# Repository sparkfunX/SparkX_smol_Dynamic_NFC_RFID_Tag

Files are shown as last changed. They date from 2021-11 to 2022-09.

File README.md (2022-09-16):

# SparkX smôl Dynamic NFC/RFID Tag

SparkX smôl Dynamic NFC/RFID Tag (SPX-18991) (https://www.sparkfun.com/products/18991)

[*SparkX smôl Dynamic NFC/RFID Tag (SPX-18991)*](https://www.sparkfun.com/products/18991)

You might be wondering why we would make an NFC/RFID tag peripheral board for smôl? The STMicroelectronics ST25FV64KC is a _**dynamic**_ Near Frequency Communication / Radio Frequency Identification tag IC with 64Kbit (8KByte) of on-board EEPROM memory. It has an I<sup>2</sup>C interface which the smôl processor board can use to read and write to the EEPROM memory. But the memory can also be read and written to over the RF link _while your smôl ecosystem is in deep sleep_! This means it is perfect for: contactless data storage and collection; and for configuration.

## Repository Contents

- **/Hardware** - Eagle design files
- **LICENSE.md** contains the licence information

## Product Versions

- [SPX-18991](https://www.sparkfun.com/products/18991) - Original SparkX Release.

## License Information

This product is _**open source**_!

Please review the LICENSE.md file for license information.

If you have any questions or concerns on licensing, please contact technical support on our [SparkFun forums](https://forum.sparkfun.com/viewforum.php?f=123).

Distributed as-is; no warranty is given.

- Your friends at SparkFun.

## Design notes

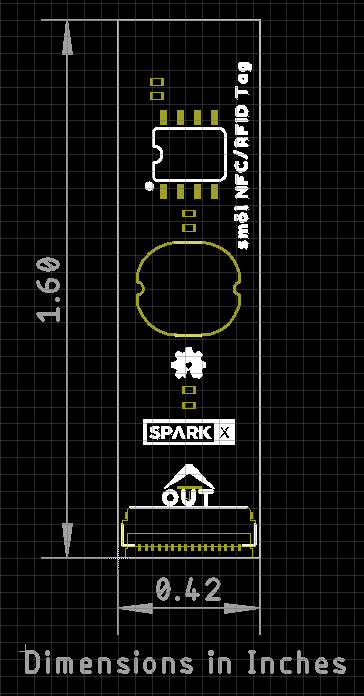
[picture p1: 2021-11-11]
img/Dimensions.png

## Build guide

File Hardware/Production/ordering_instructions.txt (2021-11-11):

panel size, 193x137mm
PCB thickness, 0.8mm
number of layers, 4
soldermask color, Black
silkscreen color, White
oz copper, 1oz
finish, HASL lead free
stencils, top+bottom
pcs per panel, 48
min trace width, 0.1524mm / 0.0060in
min drill size, 0.3000mm / 0.0118in
filename to layer stackup 1/2/3/4: GTL, GL2, GL3, GBL

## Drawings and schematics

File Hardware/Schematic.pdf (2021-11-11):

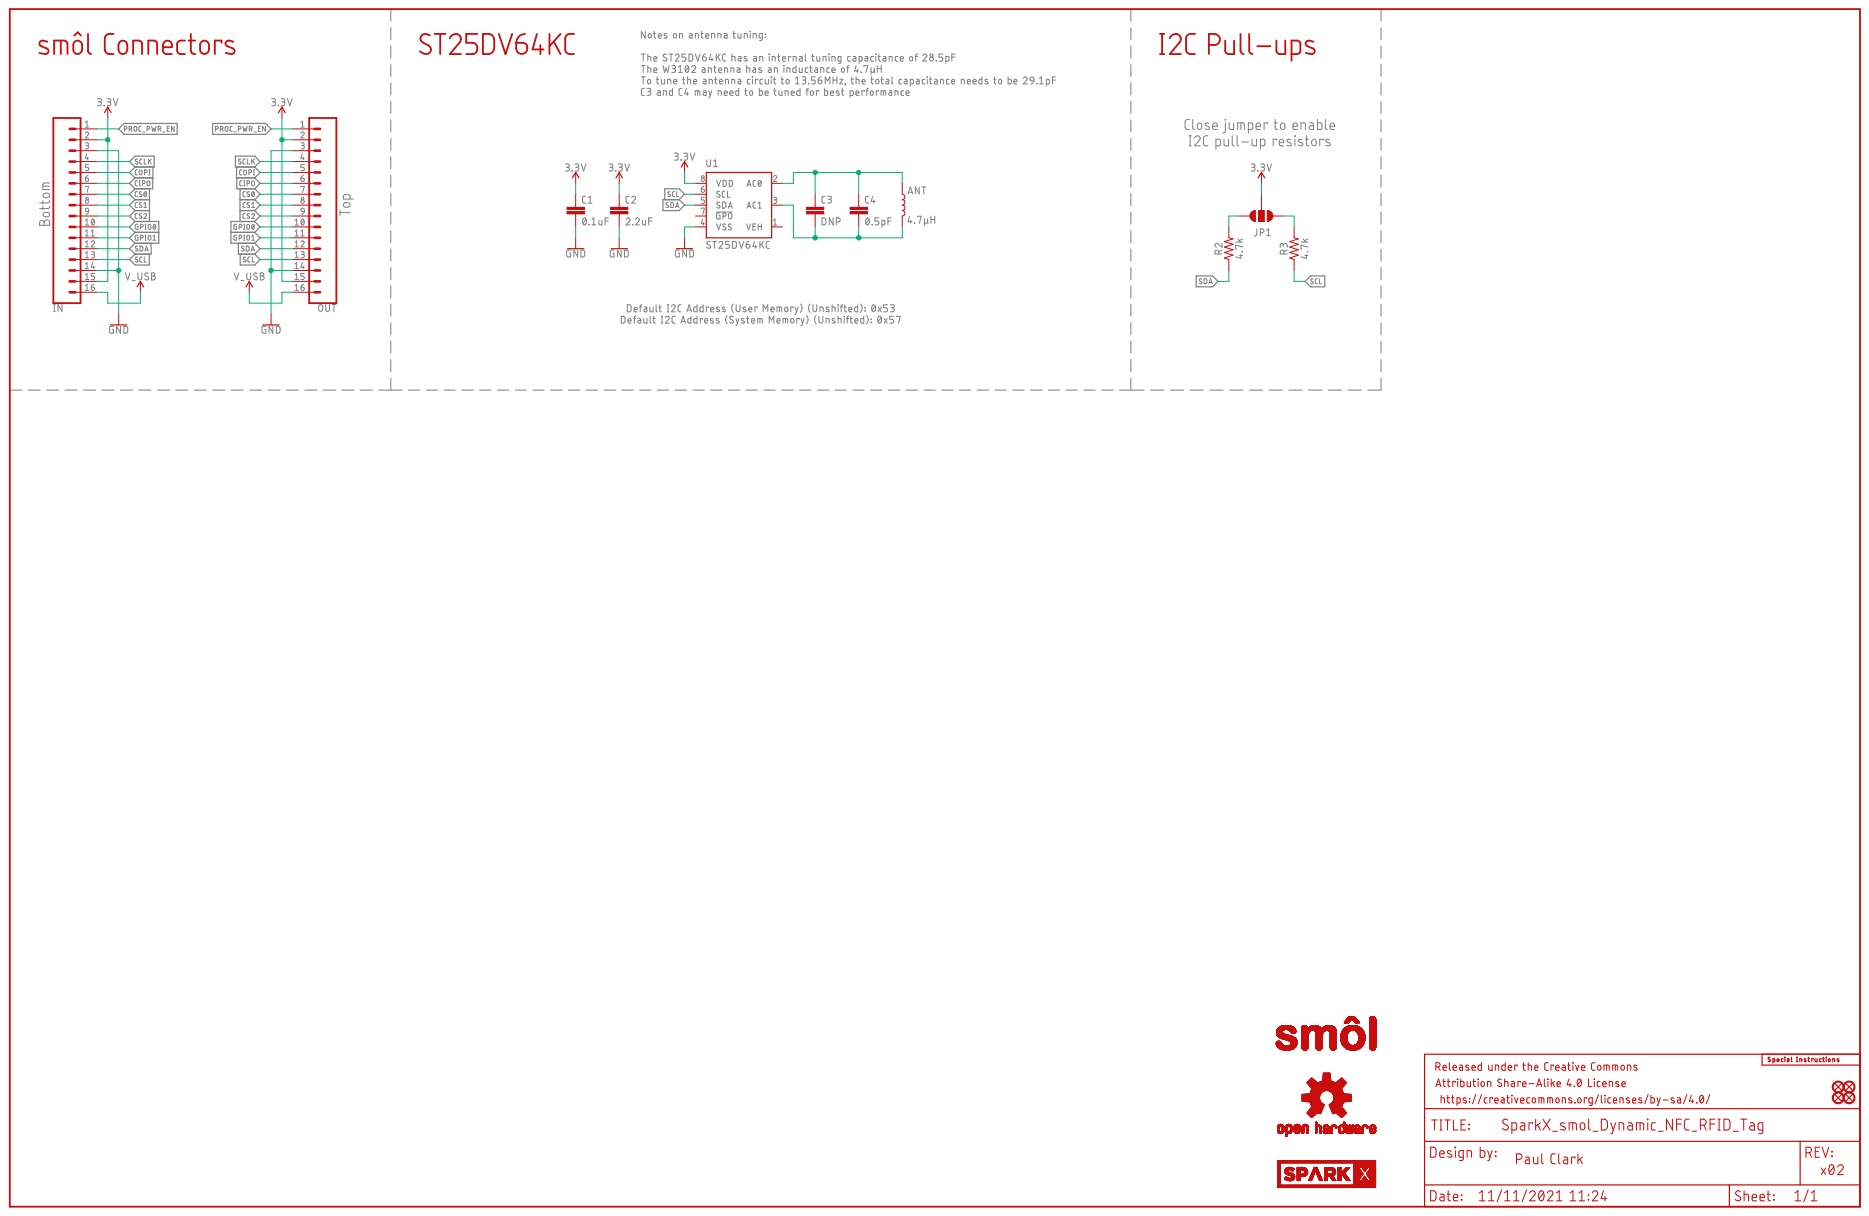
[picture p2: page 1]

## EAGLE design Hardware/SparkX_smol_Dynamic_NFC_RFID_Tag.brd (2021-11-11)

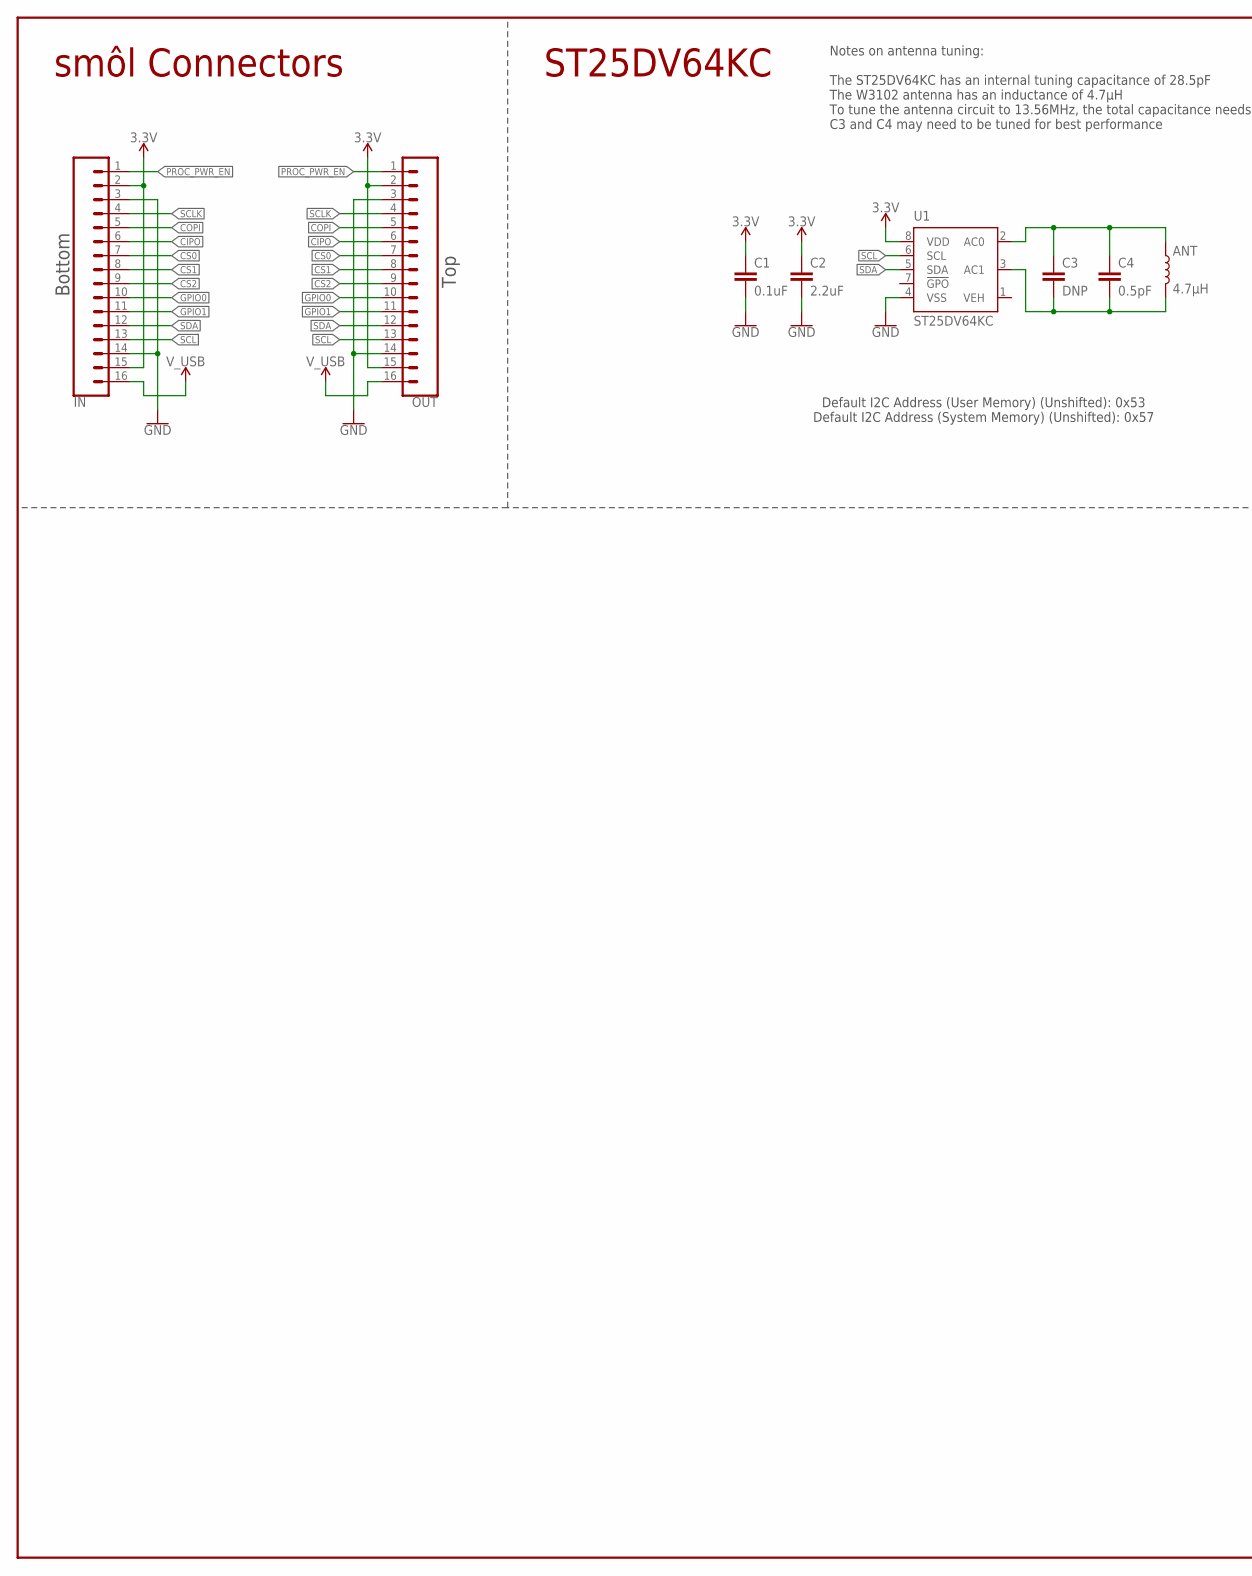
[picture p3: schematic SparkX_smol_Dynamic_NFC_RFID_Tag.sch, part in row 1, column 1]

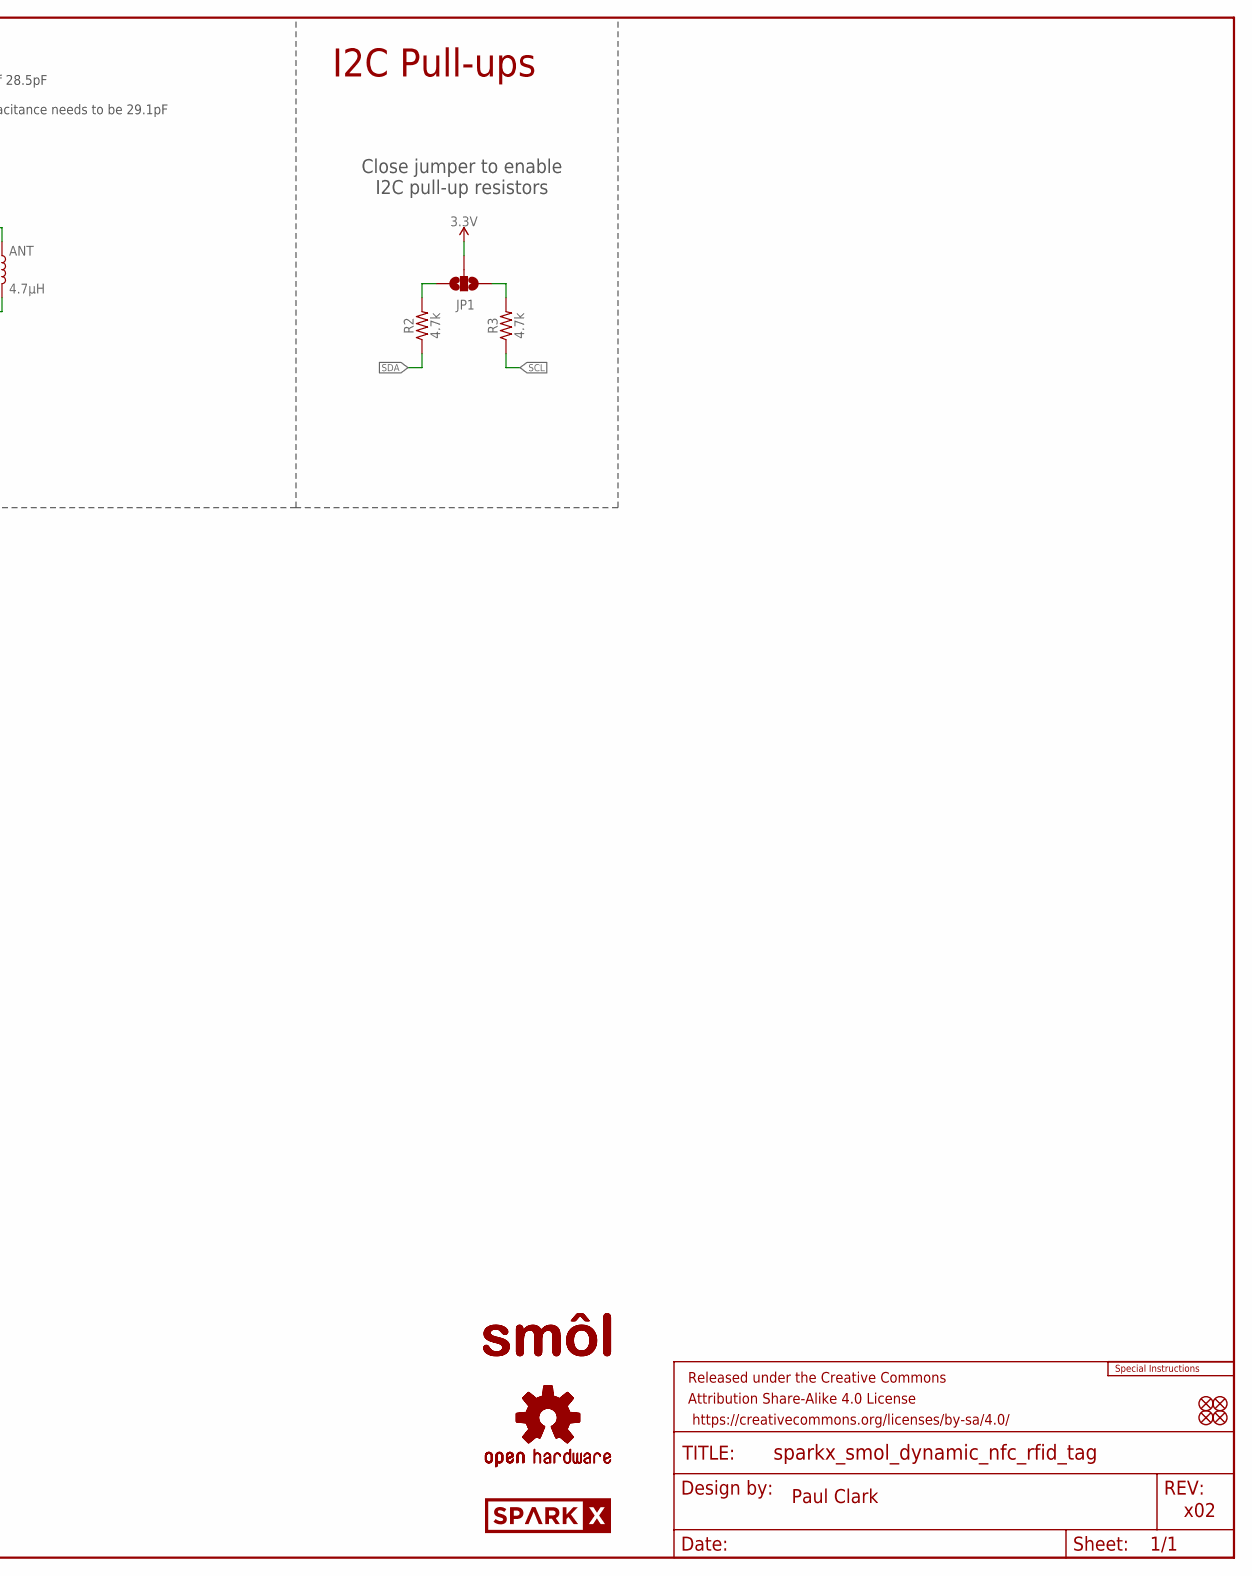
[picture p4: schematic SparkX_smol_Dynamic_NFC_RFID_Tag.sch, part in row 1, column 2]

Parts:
ANT: 4.7μH; W3102
C1: 0.1uF; 0402-TIGHT
C2: 2.2uF; 0402-TIGHT
C3: DNP; 0402-TIGHT_NO_CREAM
C4: 0.5pF; 0402-TIGHT
FD1, FD2, FD3, FD4: FIDUCIALUFIDUCIAL; FIDUCIAL-MICRO
FRAME1: FRAME-LEDGER; CREATIVE_COMMONS
IN: CONN_16FPC_16_0.5MM; FPC_16_0.5MM
JP1: JUMPER-SMT_3_NO_SILK; SMT-JUMPER_3_NO_SILK
LOGO1: SPECIAL_INSTRUCTIONS-ORDERING; ORDERING_INSTRUCTIONS
LOGO2, LOGO3: OSHW-LOGOMINI; OSHW-LOGO-MINI
OUT: CONN_16FPC_16_0.5MM; FPC_16_0.5MM
R2, R3: 4.7k; 0402-TIGHT
U1: ST25DV64KC; SO08
U$1: SPARKX-LOGO3; SPARKX-SMALL
U$3, U$9: SMOL_LOGOSMALL; SMOL_SMALL

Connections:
3.3V: C1.1, C2.1, IN.2, IN.15, JP1.2, OUT.2, OUT.15, U1.8 (VDD)
CIPO: IN.6, OUT.6
COPI: IN.5, OUT.5
CS0: IN.7, OUT.7
CS1: IN.8, OUT.8
CS2: IN.9, OUT.9
GND: C1.2, C2.2, IN.3, IN.14, OUT.3, OUT.14, U1.4 (VSS)
GPIO0: IN.10, OUT.10
GPIO1: IN.11, OUT.11
unnamed: ANT.2, C3.2, C4.2, U1.3 (AC1)
unnamed: ANT.1, C3.1, C4.1, U1.2 (AC0)
unnamed: JP1.3, R2.2
unnamed: JP1.1, R3.2
PROC_PWR_EN: IN.1, OUT.1
SCL: IN.13, OUT.13, R3.1, U1.6 (SCL)
SCLK: IN.4, OUT.4
SDA: IN.12, OUT.12, R2.1, U1.5 (SDA)
VEH: U1.1 (VEH)
V_USB: IN.16, OUT.16

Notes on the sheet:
Paul Clark
x02
smôl Connectors
Top
Bottom
ST25DV64KC
Default I2C Address (User Memory) (Unshifted): 0x53 Default I2C Address (System Memory) (Unshifted): 0x57
Notes on antenna tuning: The ST25DV64KC has an internal tuning capacitance of 28.5pF The W3102 antenna has an inductance of 4.7µH To tune the antenna circuit to 13.56MHz, the total capacitance needs to be 29.1pF C3 and C4 may need to be tuned for best performance
Close jumper to enable I2C pull-up resistors
I2C Pull-ups

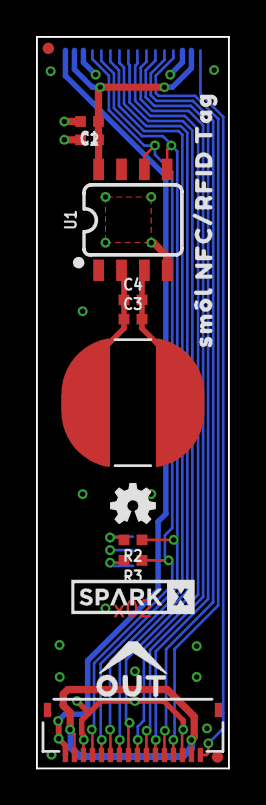
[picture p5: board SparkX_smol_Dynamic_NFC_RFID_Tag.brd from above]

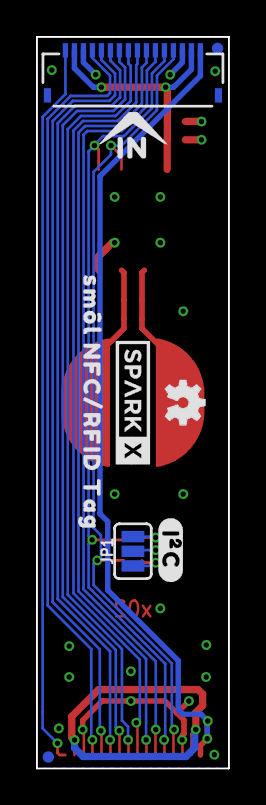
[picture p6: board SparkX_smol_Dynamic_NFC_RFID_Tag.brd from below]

Board: 4 copper layers, 10.7 x 40.6 mm, 28 parts (10 on the bottom side), 18 nets.

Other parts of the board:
U$2, U$4: SM�L_NFC#RFID_TAG0
U$5: #I�C#0
U$8: IN0
U$17: OUT0
U$20: SPARKX-LOGO3; SPARKX-SMALL

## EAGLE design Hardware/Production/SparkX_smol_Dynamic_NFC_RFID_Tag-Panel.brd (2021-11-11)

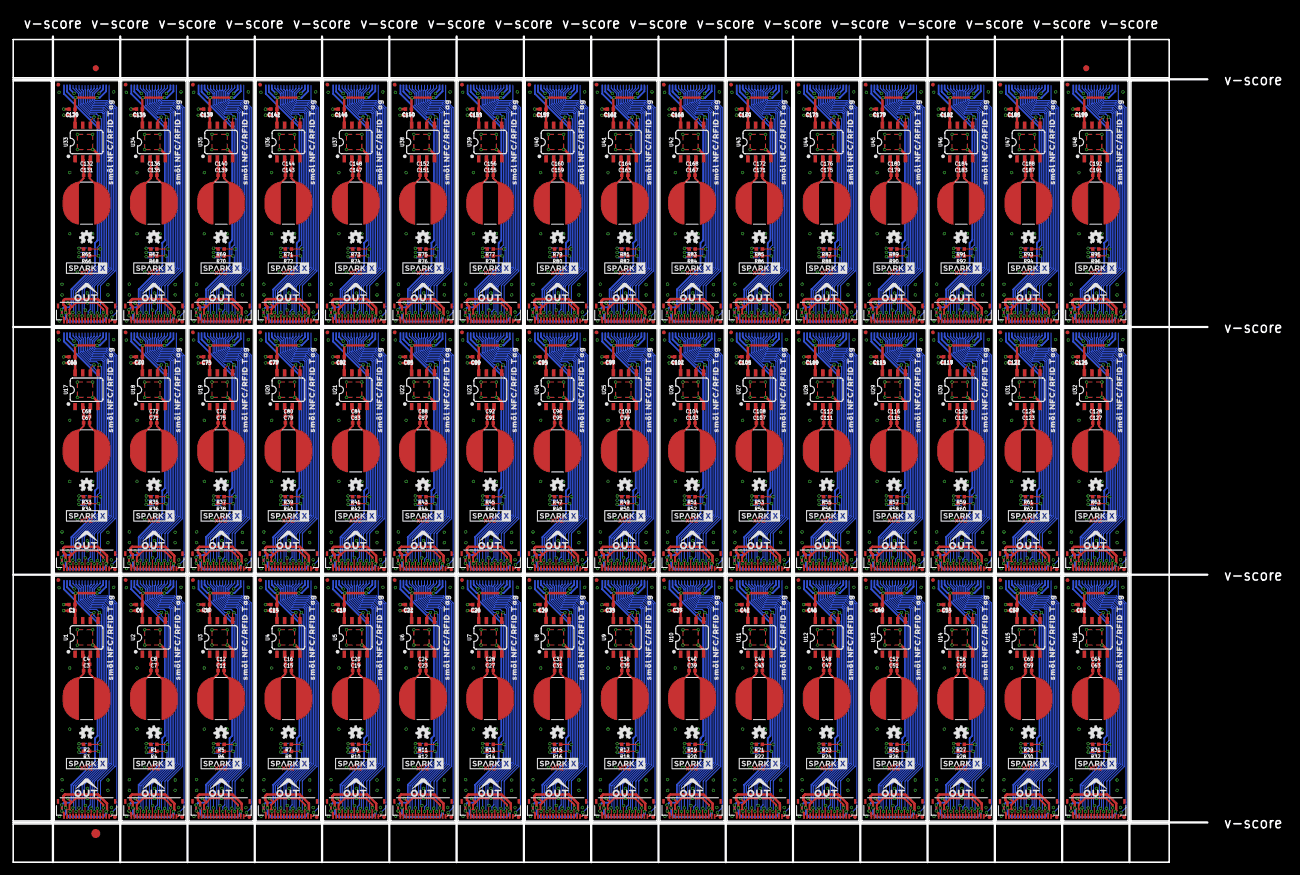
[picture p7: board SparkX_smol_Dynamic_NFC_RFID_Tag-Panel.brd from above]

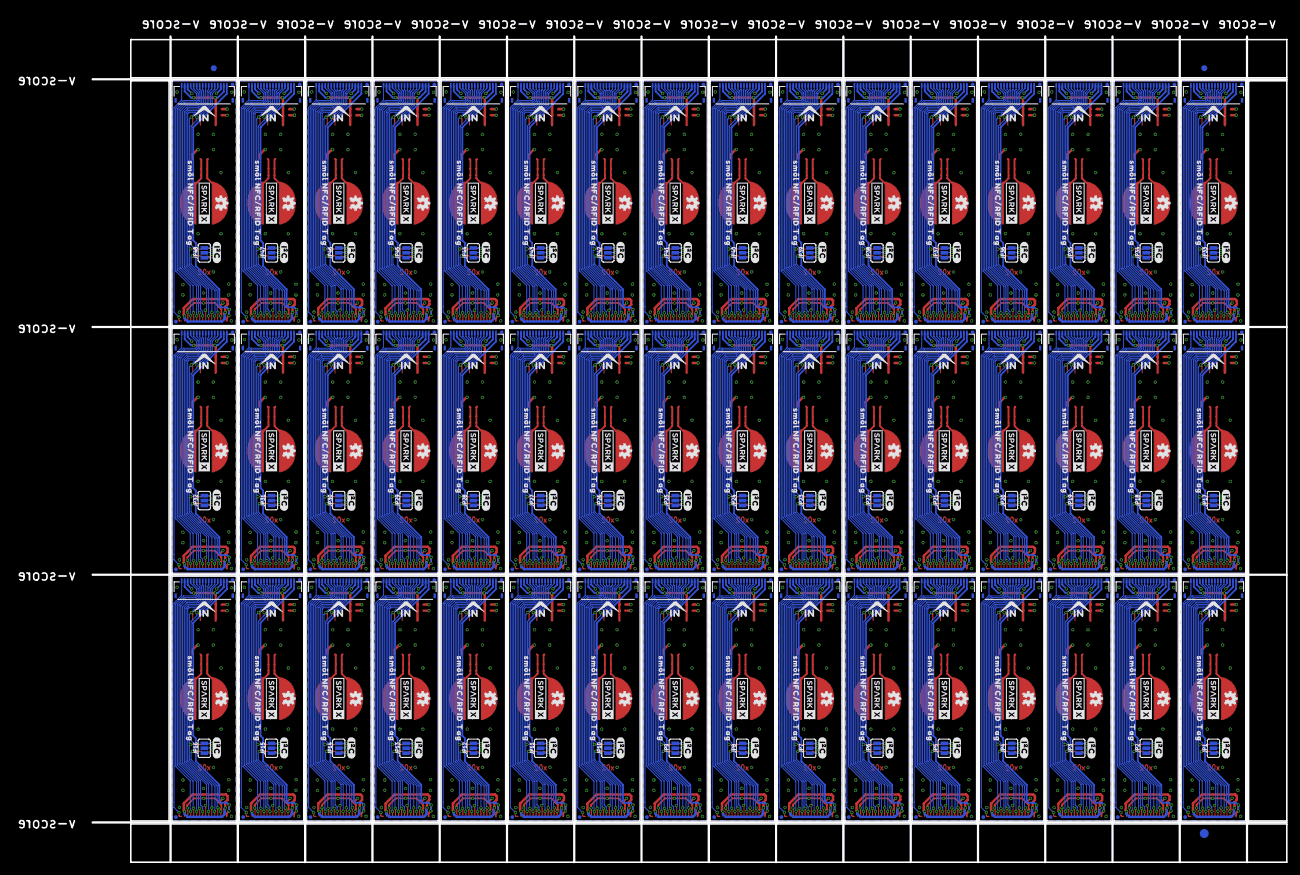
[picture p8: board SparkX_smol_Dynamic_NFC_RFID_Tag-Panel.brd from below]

Board: 4 copper layers, 198.4 x 137.2 mm, 1254 parts (483 on the bottom side), 864 nets.

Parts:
ANT, ANT1, ANT2, ANT3, ANT4, ANT5, ANT6, ANT7, ANT8, ANT9, ANT10, ANT11, ANT12, ANT13, ANT14, ANT15, ANT16, ANT17, ANT18, ANT19, ANT20, ANT21, ANT22, ANT23, ANT24, ANT25, ANT26, ANT27, ANT28, ANT29, ANT30, ANT31, ANT32, ANT33, ANT34, ANT35, ANT36, ANT37, ANT38, ANT39, ANT40, ANT41, ANT42, ANT43, ANT44, ANT45, ANT46, ANT47: 4.7μH; W3102
C1, C6, C10, C14, C18, C22, C26, C30, C34, C38, C42, C46, C50, C54, C58, C62, C66, C70, C74, C78, C82, C86, C90, C94, C98, C102, C106, C110, C114, C118, C122, C126, C130, C134, C138, C142, C146, C150, C154, C158, C162, C166, C170, C174, C178, C182, C186, C190: 0.1uF; 0402-TIGHT
C2, C5, C9, C13, C17, C21, C25, C29, C33, C37, C41, C45, C49, C53, C57, C61, C65, C69, C73, C77, C81, C85, C89, C93, C97, C101, C105, C109, C113, C117, C121, C125, C129, C133, C137, C141, C145, C149, C153, C157, C161, C165, C169, C173, C177, C181, C185, C189: 2.2uF; 0402-TIGHT
C3, C7, C11, C15, C19, C23, C27, C31, C35, C39, C43, C47, C51, C55, C59, C63, C67, C71, C75, C79, C83, C87, C91, C95, C99, C103, C107, C111, C115, C119, C123, C127, C131, C135, C139, C143, C147, C151, C155, C159, C163, C167, C171, C175, C179, C183, C187, C191: DNP; 0402-TIGHT_NO_CREAM
C4, C8, C12, C16, C20, C24, C28, C32, C36, C40, C44, C48, C52, C56, C60, C64, C68, C72, C76, C80, C84, C88, C92, C96, C100, C104, C108, C112, C116, C120, C124, C128, C132, C136, C140, C144, C148, C152, C156, C160, C164, C168, C172, C176, C180, C184, C188, C192: 0.5pF; 0402-TIGHT
E$1, E$2, E$3, E$4: FIDUCIAL-1X2
E$5, E$6: FIDUCIAL-1.5X3
FD1, FD2, FD3, FD4, FD5, FD6, FD7, FD8, FD9, FD10, FD11, FD12, FD13, FD14, FD15, FD16, FD17, FD18, FD19, FD20, FD21, FD22, FD23, FD24, FD25, FD26, FD27, FD28, FD29, FD30, FD31, FD32, FD33, FD34, FD35, FD36, FD37, FD38, FD39, FD40, FD41, FD42, FD43, FD44, FD45, FD46, FD47, FD48, FD49, FD50, FD51, FD52, FD53, FD54, FD55, FD56, FD57, FD58, FD59, FD60, FD61, FD62, FD63, FD64, FD65, FD66, FD67, FD68, FD69, FD70, FD71, FD72, FD73, FD74, FD75, FD76, FD77, FD78, FD79, FD80, FD81, FD82, FD83, FD84, FD85, FD86, FD87, FD88, FD89, FD90, FD91, FD92, FD93, FD94, FD95, FD96, FD97, FD98, FD99, FD100, FD101, FD102, FD103, FD104, FD105, FD106, FD107, FD108, FD109, FD110, FD111, FD112, FD113, FD114, FD115, FD116, FD117, FD118, FD119, FD120, FD121, FD122, FD123, FD124, FD125, FD126, FD127, FD128, FD129, FD130, FD131, FD132, FD133, FD134, FD135, FD136, FD137, FD138, FD139, FD140, FD141, FD142, FD143, FD144, FD145, FD146, FD147, FD148, FD149, FD150, FD151, FD152, FD153, FD154, FD155, FD156, FD157, FD158, FD159, FD160, FD161, FD162, FD163, FD164, FD165, FD166, FD167, FD168, FD169, FD170, FD171, FD172, FD173, FD174, FD175, FD176, FD177, FD178, FD179, FD180, FD181, FD182, FD183, FD184, FD185, FD186, FD187, FD188, FD189, FD190, FD191, FD192: FIDUCIALUFIDUCIAL; FIDUCIAL-MICRO
IN, IN1, IN2, IN3, IN4, IN5, IN6, IN7, IN8, IN9, IN10, IN11, IN12, IN13, IN14, IN15, IN16, IN17, IN18, IN19, IN20, IN21, IN22, IN23, IN24, IN25, IN26, IN27, IN28, IN29, IN30, IN31, IN32, IN33, IN34, IN35, IN36, IN37, IN38, IN39, IN40, IN41, IN42, IN43, IN44, IN45, IN46, IN47: FPC_16_0.5MM
JP1, JP2, JP3, JP4, JP5, JP6, JP7, JP8, JP9, JP10, JP11, JP12, JP13, JP14, JP15, JP16, JP17, JP18, JP19, JP20, JP21, JP22, JP23, JP24, JP25, JP26, JP27, JP28, JP29, JP30, JP31, JP32, JP33, JP34, JP35, JP36, JP37, JP38, JP39, JP40, JP41, JP42, JP43, JP44, JP45, JP46, JP47, JP48: JUMPER-SMT_3_NO_SILK; SMT-JUMPER_3_NO_SILK
LOGO1, LOGO2, LOGO3, LOGO4, LOGO5, LOGO6, LOGO7, LOGO8, LOGO9, LOGO10, LOGO11, LOGO12, LOGO13, LOGO14, LOGO15, LOGO16, LOGO17, LOGO18, LOGO19, LOGO20, LOGO21, LOGO22, LOGO23, LOGO24, LOGO25, LOGO26, LOGO27, LOGO28, LOGO29, LOGO30, LOGO31, LOGO32, LOGO33, LOGO34, LOGO35, LOGO36, LOGO37, LOGO38, LOGO39, LOGO40, LOGO41, LOGO42, LOGO43, LOGO44, LOGO45, LOGO46, LOGO47, LOGO48, LOGO49, LOGO50, LOGO51, LOGO52, LOGO53, LOGO54, LOGO55, LOGO56, LOGO57, LOGO58, LOGO59, LOGO60, LOGO61, LOGO62, LOGO63, LOGO64, LOGO65, LOGO66, LOGO67, LOGO68, LOGO69, LOGO70, LOGO71, LOGO72, LOGO73, LOGO74, LOGO75, LOGO76, LOGO77, LOGO78, LOGO79, LOGO80, LOGO81, LOGO82, LOGO83, LOGO84, LOGO85, LOGO86, LOGO87, LOGO88, LOGO89, LOGO90, LOGO91, LOGO92, LOGO93, LOGO94, LOGO95, LOGO96: OSHW-LOGOMINI; OSHW-LOGO-MINI
OUT, OUT1, OUT2, OUT3, OUT4, OUT5, OUT6, OUT7, OUT8, OUT9, OUT10, OUT11, OUT12, OUT13, OUT14, OUT15, OUT16, OUT17, OUT18, OUT19, OUT20, OUT21, OUT22, OUT23, OUT24, OUT25, OUT26, OUT27, OUT28, OUT29, OUT30, OUT31, OUT32, OUT33, OUT34, OUT35, OUT36, OUT37, OUT38, OUT39, OUT40, OUT41, OUT42, OUT43, OUT44, OUT45, OUT46, OUT47: FPC_16_0.5MM
R1, R2, R3, R4, R5, R6, R7, R8, R9, R10, R11, R12, R13, R14, R15, R16, R17, R18, R19, R20, R21, R22, R23, R24, R25, R26, R27, R28, R29, R30, R31, R32, R33, R34, R35, R36, R37, R38, R39, R40, R41, R42, R43, R44, R45, R46, R47, R48, R49, R50, R51, R52, R53, R54, R55, R56, R57, R58, R59, R60, R61, R62, R63, R64, R65, R66, R67, R68, R69, R70, R71, R72, R73, R74, R75, R76, R77, R78, R79, R80, R81, R82, R83, R84, R85, R86, R87, R88, R89, R90, R91, R92, R93, R94, R95, R96: 4.7k; 0402-TIGHT
U1, U2, U3, U4, U5, U6, U7, U8, U9, U10, U11, U12, U13, U14, U15, U16, U17, U18, U19, U20, U21, U22, U23, U24, U25, U26, U27, U28, U29, U30, U31, U32, U33, U34, U35, U36, U37, U38, U39, U40, U41, U42, U43, U44, U45, U46, U47, U48: ST25DV64KC; SO08
U$1, U$6, U$7, U$18, U$19, U$20, U$28, U$29, U$37, U$38, U$46, U$47, U$55, U$56, U$64, U$65, U$73, U$74, U$82, U$83, U$91, U$92, U$100, U$101, U$109, U$110, U$118, U$119, U$127, U$128, U$136, U$137, U$145, U$146, U$154, U$155, U$163, U$164, U$172, U$173, U$181, U$182, U$190, U$191, U$199, U$200, U$208, U$209, U$217, U$218, U$226, U$227, U$235, U$236, U$244, U$245, U$253, U$254, U$262, U$263, U$271, U$272, U$280, U$281, U$289, U$290, U$298, U$299, U$307, U$308, U$316, U$317, U$325, U$326, U$334, U$335, U$343, U$344, U$352, U$353, U$361, U$362, U$370, U$371, U$379, U$380, U$388, U$389, U$397, U$398, U$406, U$407, U$415, U$416, U$424, U$425: SPARKX-LOGO3; SPARKX-SMALL
U$2, U$4, U$14, U$15, U$25, U$26, U$34, U$35, U$43, U$44, U$52, U$53, U$61, U$62, U$70, U$71, U$79, U$80, U$88, U$89, U$97, U$98, U$106, U$107, U$115, U$116, U$124, U$125, U$133, U$134, U$142, U$143, U$151, U$152, U$160, U$161, U$169, U$170, U$178, U$179, U$187, U$188, U$196, U$197, U$205, U$206, U$214, U$215, U$223, U$224, U$232, U$233, U$241, U$242, U$250, U$251, U$259, U$260, U$268, U$269, U$277, U$278, U$286, U$287, U$295, U$296, U$304, U$305, U$313, U$314, U$322, U$323, U$331, U$332, U$340, U$341, U$349, U$350, U$358, U$359, U$367, U$368, U$376, U$377, U$385, U$386, U$394, U$395, U$403, U$404, U$412, U$413, U$421, U$422, U$430, U$431: SM�L_NFC#RFID_TAG0
U$3, U$9, U$12, U$13, U$23, U$24, U$32, U$33, U$41, U$42, U$50, U$51, U$59, U$60, U$68, U$69, U$77, U$78, U$86, U$87, U$95, U$96, U$104, U$105, U$113, U$114, U$122, U$123, U$131, U$132, U$140, U$141, U$149, U$150, U$158, U$159, U$167, U$168, U$176, U$177, U$185, U$186, U$194, U$195, U$203, U$204, U$212, U$213, U$221, U$222, U$230, U$231, U$239, U$240, U$248, U$249, U$257, U$258, U$266, U$267, U$275, U$276, U$284, U$285, U$293, U$294, U$302, U$303, U$311, U$312, U$320, U$321, U$329, U$330, U$338, U$339, U$347, U$348, U$356, U$357, U$365, U$366, U$374, U$375, U$383, U$384, U$392, U$393, U$401, U$402, U$410, U$411, U$419, U$420, U$428, U$429: SMOL_LOGOSMALL; SMOL_SMALL
U$5, U$16, U$27, U$36, U$45, U$54, U$63, U$72, U$81, U$90, U$99, U$108, U$117, U$126, U$135, U$144, U$153, U$162, U$171, U$180, U$189, U$198, U$207, U$216, U$225, U$234, U$243, U$252, U$261, U$270, U$279, U$288, U$297, U$306, U$315, U$324, U$333, U$342, U$351, U$360, U$369, U$378, U$387, U$396, U$405, U$414, U$423, U$432: #I�C#0
U$8, U$10, U$21, U$30, U$39, U$48, U$57, U$66, U$75, U$84, U$93, U$102, U$111, U$120, U$129, U$138, U$147, U$156, U$165, U$174, U$183, U$192, U$201, U$210, U$219, U$228, U$237, U$246, U$255, U$264, U$273, U$282, U$291, U$300, U$309, U$318, U$327, U$336, U$345, U$354, U$363, U$372, U$381, U$390, U$399, U$408, U$417, U$426: IN0
U$11, U$17, U$22, U$31, U$40, U$49, U$58, U$67, U$76, U$85, U$94, U$103, U$112, U$121, U$130, U$139, U$148, U$157, U$166, U$175, U$184, U$193, U$202, U$211, U$220, U$229, U$238, U$247, U$256, U$265, U$274, U$283, U$292, U$301, U$310, U$319, U$328, U$337, U$346, U$355, U$364, U$373, U$382, U$391, U$400, U$409, U$418, U$427: OUT0

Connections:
3.3V: C1.1, C2.1, IN.2, IN.15, JP1.2, OUT.2, OUT.15, U1.8
3.3V1: C5.1, C6.1, IN1.2, IN1.15, JP2.2, OUT1.2, OUT1.15, U2.8
3.3V2: C9.1, C10.1, IN2.2, IN2.15, JP3.2, OUT2.2, OUT2.15, U3.8
3.3V3: C13.1, C14.1, IN3.2, IN3.15, JP4.2, OUT3.2, OUT3.15, U4.8
3.3V4: C17.1, C18.1, IN4.2, IN4.15, JP5.2, OUT4.2, OUT4.15, U5.8
3.3V5: C21.1, C22.1, IN5.2, IN5.15, JP6.2, OUT5.2, OUT5.15, U6.8
3.3V6: C25.1, C26.1, IN6.2, IN6.15, JP7.2, OUT6.2, OUT6.15, U7.8
3.3V7: C29.1, C30.1, IN7.2, IN7.15, JP8.2, OUT7.2, OUT7.15, U8.8
3.3V8: C33.1, C34.1, IN8.2, IN8.15, JP9.2, OUT8.2, OUT8.15, U9.8
3.3V9: C37.1, C38.1, IN9.2, IN9.15, JP10.2, OUT9.2, OUT9.15, U10.8
3.3V10: C41.1, C42.1, IN10.2, IN10.15, JP11.2, OUT10.2, OUT10.15, U11.8
3.3V11: C45.1, C46.1, IN11.2, IN11.15, JP12.2, OUT11.2, OUT11.15, U12.8
3.3V12: C49.1, C50.1, IN12.2, IN12.15, JP13.2, OUT12.2, OUT12.15, U13.8
3.3V13: C53.1, C54.1, IN13.2, IN13.15, JP14.2, OUT13.2, OUT13.15, U14.8
3.3V14: C57.1, C58.1, IN14.2, IN14.15, JP15.2, OUT14.2, OUT14.15, U15.8
3.3V15: C61.1, C62.1, IN15.2, IN15.15, JP16.2, OUT15.2, OUT15.15, U16.8
3.3V16: C65.1, C66.1, IN16.2, IN16.15, JP17.2, OUT16.2, OUT16.15, U17.8
3.3V17: C69.1, C70.1, IN17.2, IN17.15, JP18.2, OUT17.2, OUT17.15, U18.8
3.3V18: C73.1, C74.1, IN18.2, IN18.15, JP19.2, OUT18.2, OUT18.15, U19.8
3.3V19: C77.1, C78.1, IN19.2, IN19.15, JP20.2, OUT19.2, OUT19.15, U20.8
3.3V20: C81.1, C82.1, IN20.2, IN20.15, JP21.2, OUT20.2, OUT20.15, U21.8
3.3V21: C85.1, C86.1, IN21.2, IN21.15, JP22.2, OUT21.2, OUT21.15, U22.8
3.3V22: C89.1, C90.1, IN22.2, IN22.15, JP23.2, OUT22.2, OUT22.15, U23.8
3.3V23: C93.1, C94.1, IN23.2, IN23.15, JP24.2, OUT23.2, OUT23.15, U24.8
3.3V24: C97.1, C98.1, IN24.2, IN24.15, JP25.2, OUT24.2, OUT24.15, U25.8
3.3V25: C101.1, C102.1, IN25.2, IN25.15, JP26.2, OUT25.2, OUT25.15, U26.8
3.3V26: C105.1, C106.1, IN26.2, IN26.15, JP27.2, OUT26.2, OUT26.15, U27.8
3.3V27: C109.1, C110.1, IN27.2, IN27.15, JP28.2, OUT27.2, OUT27.15, U28.8
3.3V28: C113.1, C114.1, IN28.2, IN28.15, JP29.2, OUT28.2, OUT28.15, U29.8
3.3V29: C117.1, C118.1, IN29.2, IN29.15, JP30.2, OUT29.2, OUT29.15, U30.8
3.3V30: C121.1, C122.1, IN30.2, IN30.15, JP31.2, OUT30.2, OUT30.15, U31.8
3.3V31: C125.1, C126.1, IN31.2, IN31.15, JP32.2, OUT31.2, OUT31.15, U32.8
3.3V32: C129.1, C130.1, IN32.2, IN32.15, JP33.2, OUT32.2, OUT32.15, U33.8
3.3V33: C133.1, C134.1, IN33.2, IN33.15, JP34.2, OUT33.2, OUT33.15, U34.8
3.3V34: C137.1, C138.1, IN34.2, IN34.15, JP35.2, OUT34.2, OUT34.15, U35.8
3.3V35: C141.1, C142.1, IN35.2, IN35.15, JP36.2, OUT35.2, OUT35.15, U36.8
3.3V36: C145.1, C146.1, IN36.2, IN36.15, JP37.2, OUT36.2, OUT36.15, U37.8
3.3V37: C149.1, C150.1, IN37.2, IN37.15, JP38.2, OUT37.2, OUT37.15, U38.8
3.3V38: C153.1, C154.1, IN38.2, IN38.15, JP39.2, OUT38.2, OUT38.15, U39.8
3.3V39: C157.1, C158.1, IN39.2, IN39.15, JP40.2, OUT39.2, OUT39.15, U40.8
3.3V40: C161.1, C162.1, IN40.2, IN40.15, JP41.2, OUT40.2, OUT40.15, U41.8
3.3V41: C165.1, C166.1, IN41.2, IN41.15, JP42.2, OUT41.2, OUT41.15, U42.8
3.3V42: C169.1, C170.1, IN42.2, IN42.15, JP43.2, OUT42.2, OUT42.15, U43.8
3.3V43: C173.1, C174.1, IN43.2, IN43.15, JP44.2, OUT43.2, OUT43.15, U44.8
3.3V44: C177.1, C178.1, IN44.2, IN44.15, JP45.2, OUT44.2, OUT44.15, U45.8
3.3V45: C181.1, C182.1, IN45.2, IN45.15, JP46.2, OUT45.2, OUT45.15, U46.8
3.3V46: C185.1, C186.1, IN46.2, IN46.15, JP47.2, OUT46.2, OUT46.15, U47.8
3.3V47: C189.1, C190.1, IN47.2, IN47.15, JP48.2, OUT47.2, OUT47.15, U48.8
CIPO: IN.6, OUT.6
CIPO1: IN1.6, OUT1.6
CIPO2: IN2.6, OUT2.6
CIPO3: IN3.6, OUT3.6
CIPO4: IN4.6, OUT4.6
CIPO5: IN5.6, OUT5.6
CIPO6: IN6.6, OUT6.6
CIPO7: IN7.6, OUT7.6
CIPO8: IN8.6, OUT8.6
CIPO9: IN9.6, OUT9.6
CIPO10: IN10.6, OUT10.6
CIPO11: IN11.6, OUT11.6
CIPO12: IN12.6, OUT12.6
CIPO13: IN13.6, OUT13.6
CIPO14: IN14.6, OUT14.6
CIPO15: IN15.6, OUT15.6
CIPO16: IN16.6, OUT16.6
CIPO17: IN17.6, OUT17.6
CIPO18: IN18.6, OUT18.6
CIPO19: IN19.6, OUT19.6
CIPO20: IN20.6, OUT20.6
CIPO21: IN21.6, OUT21.6
CIPO22: IN22.6, OUT22.6
CIPO23: IN23.6, OUT23.6
CIPO24: IN24.6, OUT24.6
CIPO25: IN25.6, OUT25.6
CIPO26: IN26.6, OUT26.6
CIPO27: IN27.6, OUT27.6
CIPO28: IN28.6, OUT28.6
CIPO29: IN29.6, OUT29.6
CIPO30: IN30.6, OUT30.6
CIPO31: IN31.6, OUT31.6
CIPO32: IN32.6, OUT32.6
CIPO33: IN33.6, OUT33.6
CIPO34: IN34.6, OUT34.6
CIPO35: IN35.6, OUT35.6
CIPO36: IN36.6, OUT36.6
CIPO37: IN37.6, OUT37.6
CIPO38: IN38.6, OUT38.6
CIPO39: IN39.6, OUT39.6
CIPO40: IN40.6, OUT40.6
CIPO41: IN41.6, OUT41.6
CIPO42: IN42.6, OUT42.6
CIPO43: IN43.6, OUT43.6
CIPO44: IN44.6, OUT44.6
CIPO45: IN45.6, OUT45.6
CIPO46: IN46.6, OUT46.6
CIPO47: IN47.6, OUT47.6
COPI: IN.5, OUT.5
COPI1: IN1.5, OUT1.5
COPI2: IN2.5, OUT2.5
COPI3: IN3.5, OUT3.5
COPI4: IN4.5, OUT4.5
COPI5: IN5.5, OUT5.5
COPI6: IN6.5, OUT6.5
COPI7: IN7.5, OUT7.5
COPI8: IN8.5, OUT8.5
COPI9: IN9.5, OUT9.5
COPI10: IN10.5, OUT10.5
COPI11: IN11.5, OUT11.5
COPI12: IN12.5, OUT12.5
COPI13: IN13.5, OUT13.5
COPI14: IN14.5, OUT14.5
COPI15: IN15.5, OUT15.5
COPI16: IN16.5, OUT16.5
COPI17: IN17.5, OUT17.5
COPI18: IN18.5, OUT18.5
COPI19: IN19.5, OUT19.5
COPI20: IN20.5, OUT20.5
COPI21: IN21.5, OUT21.5
COPI22: IN22.5, OUT22.5
COPI23: IN23.5, OUT23.5
COPI24: IN24.5, OUT24.5
COPI25: IN25.5, OUT25.5
COPI26: IN26.5, OUT26.5
COPI27: IN27.5, OUT27.5
COPI28: IN28.5, OUT28.5
COPI29: IN29.5, OUT29.5
COPI30: IN30.5, OUT30.5
COPI31: IN31.5, OUT31.5
COPI32: IN32.5, OUT32.5
COPI33: IN33.5, OUT33.5
COPI34: IN34.5, OUT34.5
COPI35: IN35.5, OUT35.5
COPI36: IN36.5, OUT36.5
COPI37: IN37.5, OUT37.5
COPI38: IN38.5, OUT38.5
COPI39: IN39.5, OUT39.5
COPI40: IN40.5, OUT40.5
COPI41: IN41.5, OUT41.5
COPI42: IN42.5, OUT42.5
COPI43: IN43.5, OUT43.5
COPI44: IN44.5, OUT44.5
COPI45: IN45.5, OUT45.5
COPI46: IN46.5, OUT46.5
COPI47: IN47.5, OUT47.5
CS0: IN.7, OUT.7
CS1: IN.8, OUT.8
CS2: IN.9, OUT.9
CS3: IN1.7, OUT1.7
CS4: IN1.8, OUT1.8
CS5: IN1.9, OUT1.9
CS6: IN2.7, OUT2.7
CS7: IN2.8, OUT2.8
CS8: IN2.9, OUT2.9
CS9: IN3.7, OUT3.7
CS10: IN3.8, OUT3.8
CS11: IN3.9, OUT3.9
CS12: IN4.7, OUT4.7
CS13: IN4.8, OUT4.8
CS14: IN4.9, OUT4.9
CS15: IN5.7, OUT5.7
CS16: IN5.8, OUT5.8
CS17: IN5.9, OUT5.9
CS18: IN6.7, OUT6.7
CS19: IN6.8, OUT6.8
CS20: IN6.9, OUT6.9
CS21: IN7.7, OUT7.7
CS22: IN7.8, OUT7.8
CS23: IN7.9, OUT7.9
CS24: IN8.7, OUT8.7
CS25: IN8.8, OUT8.8
CS26: IN8.9, OUT8.9
CS27: IN9.7, OUT9.7
CS28: IN9.8, OUT9.8
CS29: IN9.9, OUT9.9
CS30: IN10.7, OUT10.7
CS31: IN10.8, OUT10.8
CS32: IN10.9, OUT10.9
CS33: IN11.7, OUT11.7
CS34: IN11.8, OUT11.8
CS35: IN11.9, OUT11.9
CS36: IN12.7, OUT12.7
CS37: IN12.8, OUT12.8
CS38: IN12.9, OUT12.9
CS39: IN13.7, OUT13.7
CS40: IN13.8, OUT13.8
CS41: IN13.9, OUT13.9
CS42: IN14.7, OUT14.7
CS43: IN14.8, OUT14.8
CS44: IN14.9, OUT14.9
CS45: IN15.7, OUT15.7
CS46: IN15.8, OUT15.8
CS47: IN15.9, OUT15.9
CS48: IN16.7, OUT16.7
CS49: IN16.8, OUT16.8
CS50: IN16.9, OUT16.9
CS51: IN17.7, OUT17.7
CS52: IN17.8, OUT17.8
CS53: IN17.9, OUT17.9
CS54: IN18.7, OUT18.7
CS55: IN18.8, OUT18.8
CS56: IN18.9, OUT18.9
CS57: IN19.7, OUT19.7
CS58: IN19.8, OUT19.8
CS59: IN19.9, OUT19.9
CS60: IN20.7, OUT20.7
CS61: IN20.8, OUT20.8
CS62: IN20.9, OUT20.9
CS63: IN21.7, OUT21.7
CS64: IN21.8, OUT21.8
CS65: IN21.9, OUT21.9
CS66: IN22.7, OUT22.7
CS67: IN22.8, OUT22.8
CS68: IN22.9, OUT22.9
CS69: IN23.7, OUT23.7
CS70: IN23.8, OUT23.8
CS71: IN23.9, OUT23.9
CS72: IN24.7, OUT24.7
CS73: IN24.8, OUT24.8
CS74: IN24.9, OUT24.9
CS75: IN25.7, OUT25.7
CS76: IN25.8, OUT25.8
CS77: IN25.9, OUT25.9
CS78: IN26.7, OUT26.7
CS79: IN26.8, OUT26.8
CS80: IN26.9, OUT26.9
CS81: IN27.7, OUT27.7
CS82: IN27.8, OUT27.8
CS83: IN27.9, OUT27.9
CS84: IN28.7, OUT28.7
CS85: IN28.8, OUT28.8
CS86: IN28.9, OUT28.9
CS87: IN29.7, OUT29.7
CS88: IN29.8, OUT29.8
CS89: IN29.9, OUT29.9
CS90: IN30.7, OUT30.7
CS91: IN30.8, OUT30.8
CS92: IN30.9, OUT30.9
CS93: IN31.7, OUT31.7
CS94: IN31.8, OUT31.8
CS95: IN31.9, OUT31.9
CS96: IN32.7, OUT32.7
CS97: IN32.8, OUT32.8
CS98: IN32.9, OUT32.9
CS99: IN33.7, OUT33.7
CS100: IN33.8, OUT33.8
CS101: IN33.9, OUT33.9
CS102: IN34.7, OUT34.7
CS103: IN34.8, OUT34.8
CS104: IN34.9, OUT34.9
CS105: IN35.7, OUT35.7
CS106: IN35.8, OUT35.8
CS107: IN35.9, OUT35.9
CS108: IN36.7, OUT36.7
CS109: IN36.8, OUT36.8
CS110: IN36.9, OUT36.9
CS111: IN37.7, OUT37.7
CS112: IN37.8, OUT37.8
CS113: IN37.9, OUT37.9
CS114: IN38.7, OUT38.7
CS115: IN38.8, OUT38.8
CS116: IN38.9, OUT38.9
CS117: IN39.7, OUT39.7
CS118: IN39.8, OUT39.8
CS119: IN39.9, OUT39.9
CS120: IN40.7, OUT40.7
CS121: IN40.8, OUT40.8
CS122: IN40.9, OUT40.9
CS123: IN41.7, OUT41.7
CS124: IN41.8, OUT41.8
CS125: IN41.9, OUT41.9
CS126: IN42.7, OUT42.7
CS127: IN42.8, OUT42.8
CS128: IN42.9, OUT42.9
CS129: IN43.7, OUT43.7
CS130: IN43.8, OUT43.8
CS131: IN43.9, OUT43.9
CS132: IN44.7, OUT44.7
CS133: IN44.8, OUT44.8
CS134: IN44.9, OUT44.9
CS135: IN45.7, OUT45.7
CS136: IN45.8, OUT45.8
CS137: IN45.9, OUT45.9
CS138: IN46.7, OUT46.7
CS139: IN46.8, OUT46.8
CS140: IN46.9, OUT46.9
CS141: IN47.7, OUT47.7
CS142: IN47.8, OUT47.8
CS143: IN47.9, OUT47.9
GND: C1.2, C2.2, IN.3, IN.14, OUT.3, OUT.14, U1.4
GND1: C5.2, C6.2, IN1.3, IN1.14, OUT1.3, OUT1.14, U2.4
GND2: C9.2, C10.2, IN2.3, IN2.14, OUT2.3, OUT2.14, U3.4
GND3: C13.2, C14.2, IN3.3, IN3.14, OUT3.3, OUT3.14, U4.4
GND4: C17.2, C18.2, IN4.3, IN4.14, OUT4.3, OUT4.14, U5.4
GND5: C21.2, C22.2, IN5.3, IN5.14, OUT5.3, OUT5.14, U6.4
GND6: C25.2, C26.2, IN6.3, IN6.14, OUT6.3, OUT6.14, U7.4
GND7: C29.2, C30.2, IN7.3, IN7.14, OUT7.3, OUT7.14, U8.4
GND8: C33.2, C34.2, IN8.3, IN8.14, OUT8.3, OUT8.14, U9.4
GND9: C37.2, C38.2, IN9.3, IN9.14, OUT9.3, OUT9.14, U10.4
GND10: C41.2, C42.2, IN10.3, IN10.14, OUT10.3, OUT10.14, U11.4
GND11: C45.2, C46.2, IN11.3, IN11.14, OUT11.3, OUT11.14, U12.4
GND12: C49.2, C50.2, IN12.3, IN12.14, OUT12.3, OUT12.14, U13.4
GND13: C53.2, C54.2, IN13.3, IN13.14, OUT13.3, OUT13.14, U14.4
GND14: C57.2, C58.2, IN14.3, IN14.14, OUT14.3, OUT14.14, U15.4
GND15: C61.2, C62.2, IN15.3, IN15.14, OUT15.3, OUT15.14, U16.4
GND16: C65.2, C66.2, IN16.3, IN16.14, OUT16.3, OUT16.14, U17.4
GND17: C69.2, C70.2, IN17.3, IN17.14, OUT17.3, OUT17.14, U18.4
GND18: C73.2, C74.2, IN18.3, IN18.14, OUT18.3, OUT18.14, U19.4
GND19: C77.2, C78.2, IN19.3, IN19.14, OUT19.3, OUT19.14, U20.4
GND20: C81.2, C82.2, IN20.3, IN20.14, OUT20.3, OUT20.14, U21.4
GND21: C85.2, C86.2, IN21.3, IN21.14, OUT21.3, OUT21.14, U22.4
GND22: C89.2, C90.2, IN22.3, IN22.14, OUT22.3, OUT22.14, U23.4
GND23: C93.2, C94.2, IN23.3, IN23.14, OUT23.3, OUT23.14, U24.4
GND24: C97.2, C98.2, IN24.3, IN24.14, OUT24.3, OUT24.14, U25.4
GND25: C101.2, C102.2, IN25.3, IN25.14, OUT25.3, OUT25.14, U26.4
GND26: C105.2, C106.2, IN26.3, IN26.14, OUT26.3, OUT26.14, U27.4
GND27: C109.2, C110.2, IN27.3, IN27.14, OUT27.3, OUT27.14, U28.4
GND28: C113.2, C114.2, IN28.3, IN28.14, OUT28.3, OUT28.14, U29.4
GND29: C117.2, C118.2, IN29.3, IN29.14, OUT29.3, OUT29.14, U30.4
GND30: C121.2, C122.2, IN30.3, IN30.14, OUT30.3, OUT30.14, U31.4
GND31: C125.2, C126.2, IN31.3, IN31.14, OUT31.3, OUT31.14, U32.4
GND32: C129.2, C130.2, IN32.3, IN32.14, OUT32.3, OUT32.14, U33.4
GND33: C133.2, C134.2, IN33.3, IN33.14, OUT33.3, OUT33.14, U34.4
GND34: C137.2, C138.2, IN34.3, IN34.14, OUT34.3, OUT34.14, U35.4
GND35: C141.2, C142.2, IN35.3, IN35.14, OUT35.3, OUT35.14, U36.4
GND36: C145.2, C146.2, IN36.3, IN36.14, OUT36.3, OUT36.14, U37.4
GND37: C149.2, C150.2, IN37.3, IN37.14, OUT37.3, OUT37.14, U38.4
GND38: C153.2, C154.2, IN38.3, IN38.14, OUT38.3, OUT38.14, U39.4
GND39: C157.2, C158.2, IN39.3, IN39.14, OUT39.3, OUT39.14, U40.4
GND40: C161.2, C162.2, IN40.3, IN40.14, OUT40.3, OUT40.14, U41.4
GND41: C165.2, C166.2, IN41.3, IN41.14, OUT41.3, OUT41.14, U42.4
GND42: C169.2, C170.2, IN42.3, IN42.14, OUT42.3, OUT42.14, U43.4
GND43: C173.2, C174.2, IN43.3, IN43.14, OUT43.3, OUT43.14, U44.4
GND44: C177.2, C178.2, IN44.3, IN44.14, OUT44.3, OUT44.14, U45.4
GND45: C181.2, C182.2, IN45.3, IN45.14, OUT45.3, OUT45.14, U46.4
GND46: C185.2, C186.2, IN46.3, IN46.14, OUT46.3, OUT46.14, U47.4
GND47: C189.2, C190.2, IN47.3, IN47.14, OUT47.3, OUT47.14, U48.4
GPIO0: IN.10, OUT.10
GPIO1: IN.11, OUT.11
GPIO2: IN1.10, OUT1.10
GPIO3: IN1.11, OUT1.11
GPIO4: IN2.10, OUT2.10
GPIO5: IN2.11, OUT2.11
GPIO6: IN3.10, OUT3.10
GPIO7: IN3.11, OUT3.11
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

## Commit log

2021-11-09 Add Eagle files
    [SparkX_smol_Dynamic_NFC_RFID_Tag-Panel.GBL, SparkX_smol_Dynamic_NFC_RFID_Tag-Panel.GBO, SparkX_smol_Dynamic_NFC_RFID_Tag-Panel.GBP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]
2021-11-10 Change to 4-layer
    [SparkX_smol_ARTIC_R2-Panel.GBO, SparkX_smol_ARTIC_R2-Panel.GBP, SparkX_smol_ARTIC_R2-Panel.GBS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]
2021-11-11 x02: change to W3102 antenna
    [SparkX_smol_ARTIC_R2-Panel.GBO, SparkX_smol_ARTIC_R2-Panel.GBP, SparkX_smol_ARTIC_R2-Panel.GBS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]
2021-11-11 Add antenna datasheet

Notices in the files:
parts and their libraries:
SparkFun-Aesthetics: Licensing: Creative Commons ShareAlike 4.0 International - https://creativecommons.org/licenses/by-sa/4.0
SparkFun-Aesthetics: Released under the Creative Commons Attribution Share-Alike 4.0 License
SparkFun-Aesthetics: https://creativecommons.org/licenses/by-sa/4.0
